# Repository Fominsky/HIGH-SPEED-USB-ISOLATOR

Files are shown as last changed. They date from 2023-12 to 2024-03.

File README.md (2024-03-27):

# High-speed USB isolator based on ADuM3165/ADuM3166

When connecting a USB device to a PC or laptop, there is a risk that the device may be faulty or may fail during operation. This is especially relevant during the development and debugging of devices that connects to your PC.

Connecting a malfunctioning USB device can easily lead to the failure of the USB hub in your PC, and in the case of laptops, the hub is often located on the same substrate as the processor. Thus, there is a risk that if something goes wrong, you will have to replace the processor in your laptop.

A USB isolator will protect your PC from USB-related issues. In the worst-case scenario, the ADuM3165/6 chip itself may fail, but your PC should be fine.

## Description
The device has 3 USB ports: Host USB, External Power USB, and Device USB.
Host USB is connected to your computer, Device USB is connected to your device that needs to be isolated, and External Power USB is connected to an external power source for powering the device connected to the Device USB port.

The device has its own low-power galvanically isolated DC-DC converter. The DC-DC converter also has converter overload protection. Therefore, the device can be used without external power for communication with low-power devices or devices that have their own power source.

The maximum current of the DC-DC converter is 200 mA. If this value is exceeded, the load is disconnected, and the "Overload" red LED lights up. The load will be disconnected either until the protection is reset by pressing SW1 button (Reset_Button) or until the USB is disconnected from the host USB and reconnected. 

To connect more powerful loads, you can use the External Power USB port. It is important to note that this USB is not isolated from the Device USB but is not electrically connected to the Host USB. A good solution would be to connect a power adapter from a mobile device to the external power USB.

When external power is connected, the built-in DC-DC converter is disabled. Note: as I mentioned before, the overload protection only works with the built-in DC-DC converter, so the overload protection is also disabled.

##

This Repository contains Gerber files, BOM, and step model. All you need to make an isolator. 





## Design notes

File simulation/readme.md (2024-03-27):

Simulation completed with https://www.falstad.com/circuit/circuitjs.html

When the load resistance is reduced below 24.8 ohms, a current greater than 200 mA flows through the load. 
The overload protection circuit triggers and turn off the transistor. 
During the operation of the protection and turning off the transistor, the simulation may experience some slight freezing.



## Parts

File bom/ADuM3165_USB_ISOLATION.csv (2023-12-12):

Source: | E:\Hardware\ADuM3165_USB_ISOLATION\ADuM3165_USB_ISOLATION_1.2\ADuM3165_USB_ISOLATION.kicad_sch
Date: | 12.12.2023 14:20:17
Tool: | Eeschema 7.0.9
Generator: | D:\Programs\KiCad\7.0\bin\scripting\plugins/bom_csv_grouped_by_value.py
Component Count: | 61
Collated Components:
Item | Qty | Reference(s) | Value | LibPart | Footprint | Datasheet | DNP | Digikey link | Name | Voltage
1 | 8 | C1, C2, C6, C7, C11, C12, C13, C14 | 0.1uF | Device:C_Small | Capacitor_SMD:C_0603_1608Metric | https://media.digikey.com/pdf/Data%20Sheets/Samsung%20PDFs/CL10B104KB8NFNC_Spec.pdf |  | https://www.digikey.fi/en/products/detail/samsung-electro-mechanics/CL10B104KB8NFNC/3890020 | CL10B104KB8NFNC | 50
2 | 2 | C3, C10 | 330pF | Device:C_Small | Capacitor_THT:C_Rect_L10.0mm_W3.0mm_P7.50mm_MKS4 | https://www.wima.de/wp-content/uploads/media/e_WIMA_FKP_3.pdf |  | https://www.digikey.fi/en/products/detail/wima/FKP3O103302B00KSSD/9370272 | FKP3O103302B00KSSD | 1000
3 | 2 | C4, C9 | 10uF | Device:C_Small | Capacitor_SMD:C_0805_2012Metric | https://media.digikey.com/pdf/Data%20Sheets/Samsung%20PDFs/CL21A106KOQNNNG_Spec.pdf |  | https://www.digikey.fi/en/products/detail/samsung-electro-mechanics/CL21A106KOQNNNG/3894417 | CL21A106KOQNNNG | 16
4 | 2 | C5, C8 | 1uF | Device:C_Small | Capacitor_SMD:C_0603_1608Metric | https://media.digikey.com/pdf/Data%20Sheets/Samsung%20PDFs/CL10A105KB8NNNC_Spec.pdf |  | https://www.digikey.fi/en/products/detail/samsung-electro-mechanics/CL10A105KB8NNNC/3887518 | CL10A105KB8NNNC | 50
5 | 2 | C15, C17 | 12pF | Device:C_Small | Capacitor_SMD:C_0603_1608Metric | http://www.passivecomponent.com/wp-content/uploads/datasheet/WTC_MLCC_General_Purpose.pdf |  | https://www.digikey.fi/en/products/detail/walsin-technology-corporation/0603N120J500CT/9354977 | 0603N120J500CT | 50
6 | 1 | D1 | Red | Device:LED | LED_SMD:LED_0603_1608Metric | https://optoelectronics.liteon.com/upload/download/DS22-2000-210/LTST-S270KRKT.pdf |  | https://www.digikey.fi/en/products/detail/liteon/LTST-S270KRKT/386895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 | LTST-S270KRKT
7 | 2 | D2, D5 | 10v 3A | Device:D_Schottky | Diode_SMD:D_SOD-323 | https://www.infineon.com/dgdl/bat60bseries.pdf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 |  | https://www.digikey.fi/en/products/detail/infineon-technologies/BAT60BE6327HTSA1/1280935 | BAT60BE6327HTSA1 | 10v
8 | 1 | D3 | Blue | Device:LED | LED_SMD:LED_0603_1608Metric | https://optoelectronics.liteon.com/upload/download/DS22-2000-175/LTST-S270TBKT.pdf |  | https://www.digikey.fi/en/products/detail/lite-on-inc/ltst-s270tbkt/573548 | LTST-S270TBKT
9 | 1 | D4 | Green | Device:LED | LED_SMD:LED_0603_1608Metric | https://optoelectronics.liteon.com/upload/download/DS22-2000-226/LTST-S270KGKT.pdf |  | https://www.digikey.fi/en/products/detail/lite-on-inc/ltst-s270kgkt/386893 | LTST-S270KGKT
10 | 1 | D6 | Or | Device:LED | LED_SMD:LED_0603_1608Metric | https://optoelectronics.liteon.com/upload/download/DS22-2000-209/LTST-S270KFKT.pdf |  | https://www.digikey.fi/en/products/detail/lite-on-inc/ltst-s270kfkt/386891 | LTST-S270KFKT
11 | 1 | DCDC1 | RFMM-0505S | User_lib:RFMM-0505S | User_Lib:RFMM_RFB0505S | https://recom-power.com/pdf/Econoline/RFMM.pdf |  | https://www.digikey.fi/en/products/detail/recom-power/RFMM-0505S/8550768?s=N4IgTCBcDaIEoDECySC0AGArFgyiAugL5A | RFMM-0505S
12 | 2 | J1, J2 | USB_C_Receptacle_USB2.0 | Connector:USB_C_Receptacle_USB2.0 | Connector_USB:USB_C_Receptacle_GCT_USB4105-xx-A_16P_TopMnt_Horizontal | https://gct.co/files/drawings/usb4105.pdf |  | https://www.digikey.fi/en/products/detail/gct/USB4105-GF-A/11198441 | USB4105-GF-A
13 | 1 | J3 | USB_A | Connector:USB_A | Connector_USB:USB_A_CONNFLY_DS1095-WNR0 | http://www.on-shore.com/wp-content/uploads/USB-A1HSXX.pdf |  | https://www.digikey.fi/en/products/detail/on-shore-technology-inc/USB-A1HSW6/2677750 | USB-A1HSW6
14 | 1 | L1 | 22 uH | pspice:INDUCTOR | Inductor_SMD:L_Taiyo-Yuden_MD-3030 | https://www.yuden.co.jp/productdata/catalog/wound04_e.pdf |  | https://www.digikey.fi/en/products/detail/taiyo-yuden/NR3015T220M/958032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 | NR3015T220M
15 | 1 | Q1 | AS2302 | Transistor_FET:DMN2230U | Package_TO_SOT_SMD:SOT-23 | https://media.digikey.com/pdf/Data%20Sheets/Anbon%20Semi%20PDFs/AS2302.pdf |  | https://www.digikey.fi/en/products/detail/anbon-semiconductor-int-l-limited/AS2302/16708469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 | AS2302 | 20V 3A
16 | 7 | R1, R3, R10, R15, R18, R25, R26 | 5k1 | Device:R | Resistor_SMD:R_0603_1608Metric | https://www.seielect.com/Catalog/SEI-RNCP.pdf |  | https://www.digikey.fi/en/products/detail/stackpole-electronics-inc/RNCP0603FTD1K00/2240106 | RNCP0603FTD1K00
17 | 7 | R2, R5, R6, R7, R12, R13, R14 | 1k | Device:R | Resistor_SMD:R_0603_1608Metric | https://www.seielect.com/Catalog/SEI-RNCP.pdf |  | https://www.digikey.fi/en/products/detail/stackpole-electronics-inc/RNCP0603FTD1K00/2240106 | RNCP0603FTD1K00
18 | 3 | R4, R11, R23 | 1.8k | Device:R | Resistor_SMD:R_0603_1608Metric | https://www.yageo.com/upload/media/product/productsearch/datasheet/rchip/PYu-RC_Group_51_RoHS_L_12.pdf |  | https://www.digikey.fi/en/products/detail/yageo/RC0603FR-101K8L/14008224 | RC0603FR-101K8L
19 | 3 | R8, R16, R19 | 24k | Device:R | Resistor_SMD:R_0603_1608Metric | https://www.yageo.com/upload/media/product/productsearch/datasheet/rchip/PYu-RC_Group_51_RoHS_L_12.pdf |  | https://www.digikey.fi/en/products/detail/yageo/RC0603FR-0724KL/727076 | RC0603FR-0724KL
20 | 1 | R17 | 560 | Device:R | Resistor_SMD:R_0603_1608Metric | https://www.yageo.com/upload/media/product/productsearch/datasheet/rchip/PYu-RC_Group_51_RoHS_L_12.pdf |  | https://www.digikey.fi/en/products/detail/yageo/RC0603JR-07560RL/726805 | RC0603JR-07560RL
21 | 2 | R20, R21 | 1 | Device:R | Resistor_SMD:R_0603_1608Metric | https://www.yageo.com/upload/media/product/productsearch/datasheet/rchip/PYu-AC_51_RoHS_L_9.pdf |  | https://www.digikey.fi/en/products/detail/yageo/AC0603FR-071RL/5895901 | AC0603FR-071RL
22 | 2 | R24, R27 | 0 | Device:R | Resistor_SMD:R_0603_1608Metric | https://www.yageo.com/upload/media/product/productsearch/datasheet/rchip/PYu-RC_Group_51_RoHS_L_12.pdf |  | https://www.digikey.fi/en/products/detail/yageo/RC0603JR-070RL/726675 | RC0603JR-070RL
23 | 1 | SW1 | Reset_Button | Switch:SW_Push | Button_Switch_THT:SW_Tactile_SPST_Angled_PTS645Vx58-2LFS | https://spec_sheets.e-switch.com/specs/P010309.pdf |  | https://www.digikey.fi/en/products/detail/e-switch/TL1105VF160Q/378974 | TL1105VF160Q
24 | 1 | U1 | MCP6004T-E/SL | Amplifier_Operational:MCP6004 | Package_SO:SOIC-14_3.9x8.7mm_P1.27mm | http://ww1.microchip.com/downloads/en/DeviceDoc/21733j.pdf |  | https://www.digikey.fi/en/products/detail/microchip-technology/MCP6004T-E-SL/683203 | MCP6004T-E/SL
25 | 1 | U2 | LTV-356T | Isolator:LTV-356T | Package_SO:SO-4_4.4x3.6mm_P2.54mm | http://optoelectronics.liteon.com/upload/download/DS70-2001-010/S_110_LTV-356T%2020140520.pdf |  | https://www.digikey.fi/en/products/detail/liteon/LTV-356T/385804 | LTV-356T
26 | 3 | U3, U5, U6 | D5V0P4UR6SO-7 | Power_Protection:NUP4202 | Package_TO_SOT_SMD:SOT-23-6 | https://www.digikey.fi/en/products/detail/diodes-incorporated/D5V0P4UR6SO-7/6052565 |  | https://www.digikey.fi/en/products/detail/diodes-incorporated/D5V0P4UR6SO-7/6052565 | D5V0P4UR6SO-7
27 | 1 | U4 | ADuM3165 | User_lib:ADuM3165 | Package_SO:SSOP-20_5.3x7.2mm_P0.65mm | https://au.mouser.com/datasheet/2/609/adum3165_3166-2946864.pdf |  | https://www.digikey.fi/en/products/detail/analog-devices-inc/ADUM3165BRSZ/16580732 | ADuM3165
28 | 1 | Y1 | 24MHz | Device:Crystal_GND24 | Crystal:Crystal_SMD_2016-4Pin_2.0x1.6mm | https://ecsxtal.com/store/pdf/ECX-1637B.pdf |  | https://www.digikey.fi/en/products/detail/ecs-inc/ECS-240-12-37B-CKY-TR/9838851 | ECS-240-12-37B-CKY-TR

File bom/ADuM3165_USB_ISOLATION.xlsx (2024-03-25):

Column1 | Column2 | Column3 | Column10 | Column4 | Column9 | Column11
Source: | E:\Hardware\ADuM3165_USB_ISOLATION\ADuM3165_USB_ISOLATION_1.2\ADuM3165_USB_ISOLATION.kicad_sch
Date: | 12.12.2023 14:20:17
Tool: | Eeschema 7.0.9
Generator: | D:\Programs\KiCad\7.0\bin\scripting\plugins/bom_csv_grouped_by_value.py
Component Count: | 61
Collated Components:
Item | Qty | Reference(s) | Name | Value | Digikey link | Voltage
1 | 8 | C1, C2, C6, C7, C11, C12, C13, C14 | CL10B104KB8NFNC | 0.1uF | https://www.digikey.fi/en/products/detail/samsung-electro-mechanics/CL10B104KB8NFNC/3890020 | 50
2 | 2 | C3, C10 | FKP3O103302B00KSSD | 330pF | https://www.digikey.fi/en/products/detail/wima/FKP3O103302B00KSSD/9370272 | 1000
3 | 2 | C4, C9 | CL21A106KOQNNNG | 10uF | https://www.digikey.fi/en/products/detail/samsung-electro-mechanics/CL21A106KOQNNNG/3894417 | 16
4 | 2 | C5, C8 | CL10A105KB8NNNC | 1uF | https://www.digikey.fi/en/products/detail/samsung-electro-mechanics/CL10A105KB8NNNC/3887518 | 50
5 | 2 | C15, C17 | 0603N120J500CT | 12pF | https://www.digikey.fi/en/products/detail/walsin-technology-corporation/0603N120J500CT/9354977 | 50
6 | 1 | D1 | LTST-S270KRKT | Red | https://www.digikey.fi/en/products/detail/liteon/LTST-S270KRKT/386895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
7 | 2 | D2, D5 | BAT60BE6327HTSA1 | 10v 3A | https://www.digikey.fi/en/products/detail/infineon-technologies/BAT60BE6327HTSA1/1280935 | 10v
8 | 1 | D3 | LTST-S270TBKT | Blue | https://www.digikey.fi/en/products/detail/lite-on-inc/ltst-s270tbkt/573548
9 | 1 | D4 | LTST-S270KGKT | Green | https://www.digikey.fi/en/products/detail/lite-on-inc/ltst-s270kgkt/386893
10 | 1 | D6 | LTST-S270KFKT | Or | https://www.digikey.fi/en/products/detail/lite-on-inc/ltst-s270kfkt/386891
11 | 1 | DCDC1 | RFMM-0505S | RFMM-0505S | https://www.digikey.fi/en/products/detail/recom-power/RFMM-0505S/8550768?s=N4IgTCBcDaIEoDECySC0AGArFgyiAugL5A
12 | 2 | J1, J2 | USB4105-GF-A | USB_C_Receptacle_USB2.0 | https://www.digikey.fi/en/products/detail/gct/USB4105-GF-A/11198441
13 | 1 | J3 | USB-A1HSW6 | USB_A | https://www.digikey.fi/en/products/detail/on-shore-technology-inc/USB-A1HSW6/2677750
14 | 1 | L1 | NR3015T220M | 22 uH | https://www.digikey.fi/en/products/detail/taiyo-yuden/NR3015T220M/958032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
15 | 1 | Q1 | AS2302 | AS2302 | https://www.digikey.fi/en/products/detail/anbon-semiconductor-int-l-limited/AS2302/16708469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 | 20V 3A
16 | 7 | R1, R3, R10, R15, R18, R25, R26 | RNCP0603FTD1K00 | 5k1 | https://www.digikey.fi/en/products/detail/stackpole-electronics-inc/RNCP0603FTD1K00/2240106
17 | 7 | R2, R5, R6, R7, R12, R13, R14 | RNCP0603FTD1K00 | 1k | https://www.digikey.fi/en/products/detail/stackpole-electronics-inc/RNCP0603FTD1K00/2240106
18 | 3 | R4, R11, R23 | RC0603FR-101K8L | 1.8k | https://www.digikey.fi/en/products/detail/yageo/RC0603FR-101K8L/14008224
19 | 3 | R8, R16, R19 | RC0603FR-0724KL | 24k | https://www.digikey.fi/en/products/detail/yageo/RC0603FR-0724KL/727076
20 | 1 | R17 | RC0603JR-07560RL | 560 | https://www.digikey.fi/en/products/detail/yageo/RC0603JR-07560RL/726805
21 | 2 | R20, R21 | AC0603FR-071RL | 1 | https://www.digikey.fi/en/products/detail/yageo/AC0603FR-071RL/5895901
22 | 2 | R24, R27 | RC0603JR-070RL | 0 | https://www.digikey.fi/en/products/detail/yageo/RC0603JR-070RL/726675
23 | 1 | SW1 | TL1105VF160Q | Reset_Button | https://www.digikey.fi/en/products/detail/e-switch/TL1105VF160Q/378974
24 | 1 | U1 | MCP6004T-E/SL | MCP6004T-E/SL | https://www.digikey.fi/en/products/detail/microchip-technology/MCP6004T-E-SL/683203
25 | 1 | U2 | LTV-356T | LTV-356T | https://www.digikey.fi/en/products/detail/liteon/LTV-356T/385804
26 | 3 | U3, U5, U6 | D5V0P4UR6SO-7 | D5V0P4UR6SO-7 | https://www.digikey.fi/en/products/detail/diodes-incorporated/D5V0P4UR6SO-7/6052565
27 | 1 | U4 | ADuM3165 | ADuM3165 | https://www.digikey.fi/en/products/detail/analog-devices-inc/ADUM3165BRSZ/16580732
28 | 1 | Y1 | ECS-240-12-37B-CKY-TR | 24MHz | https://www.digikey.fi/en/products/detail/ecs-inc/ECS-240-12-37B-CKY-TR/9838851

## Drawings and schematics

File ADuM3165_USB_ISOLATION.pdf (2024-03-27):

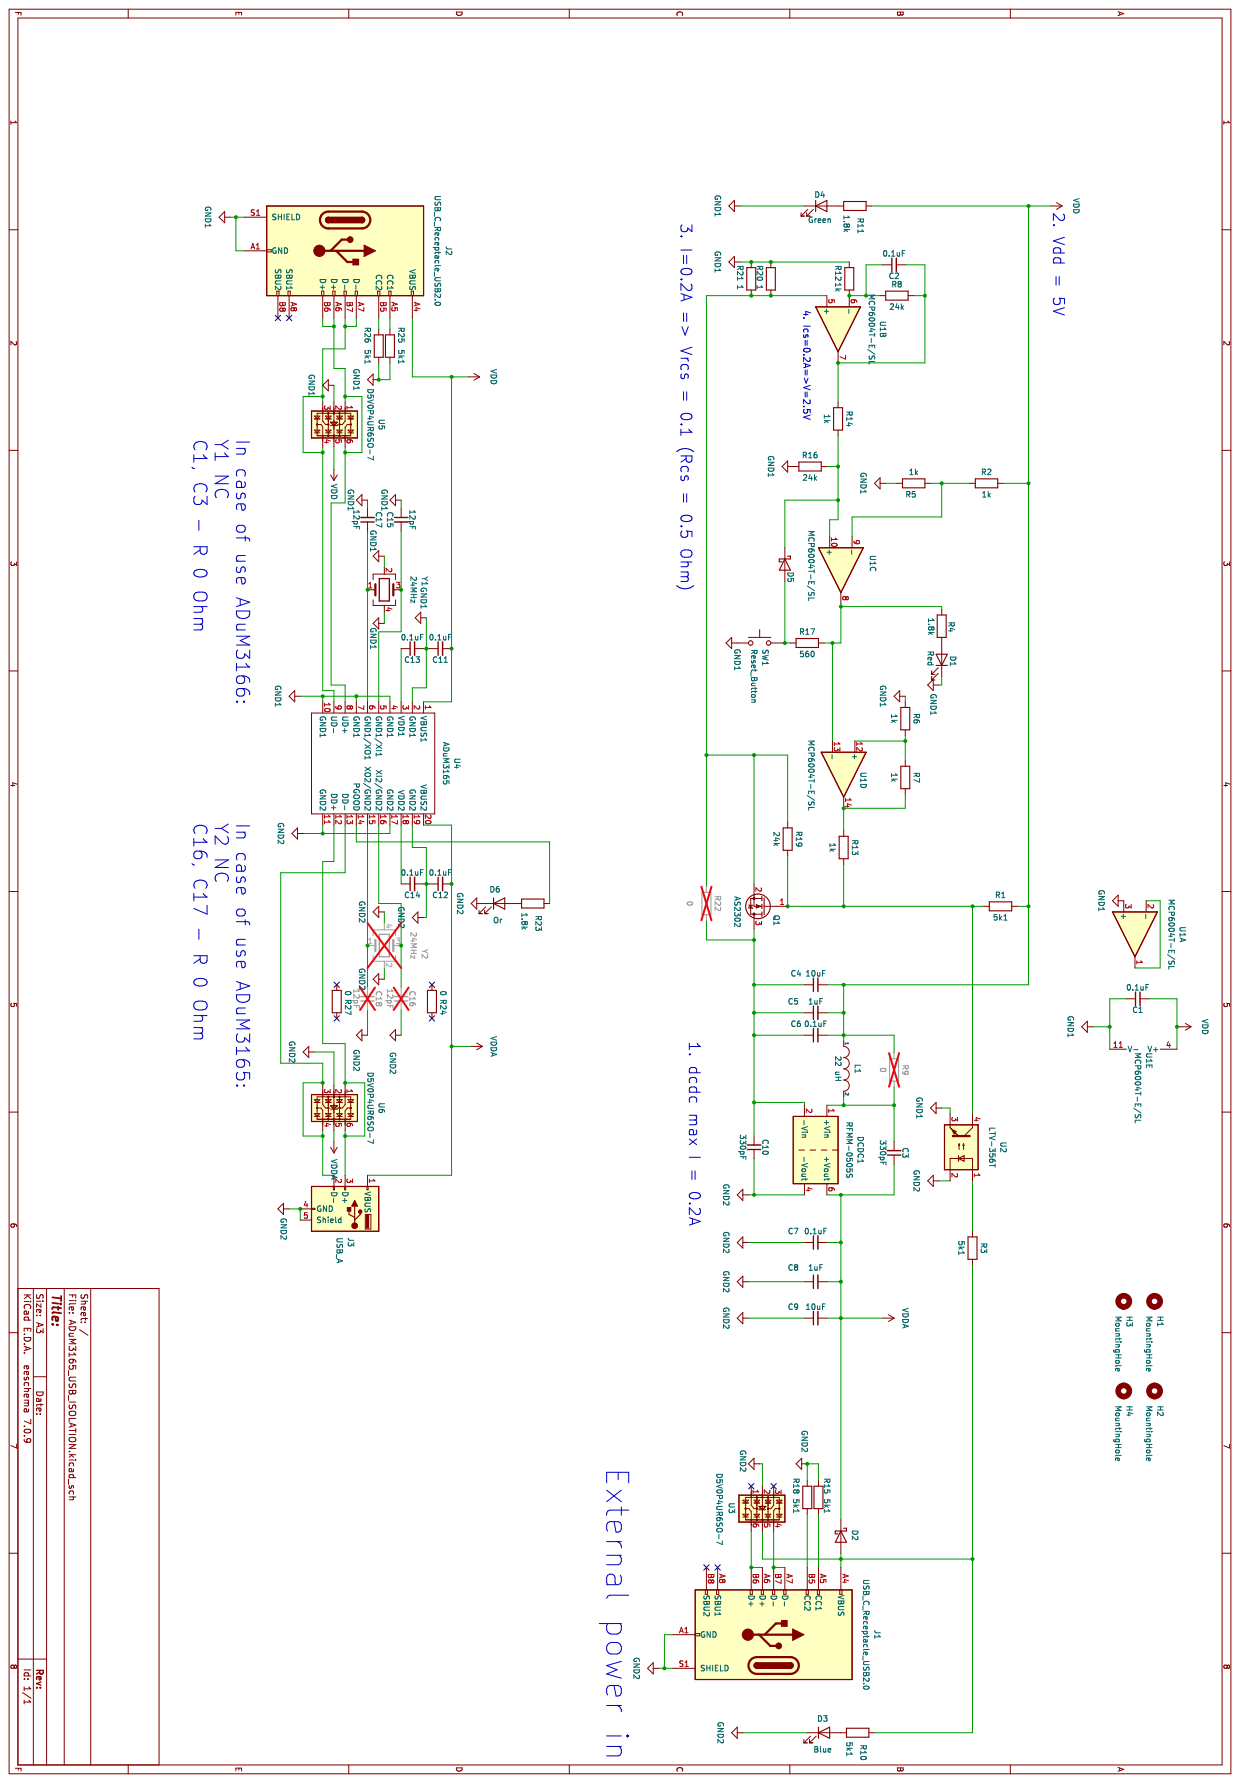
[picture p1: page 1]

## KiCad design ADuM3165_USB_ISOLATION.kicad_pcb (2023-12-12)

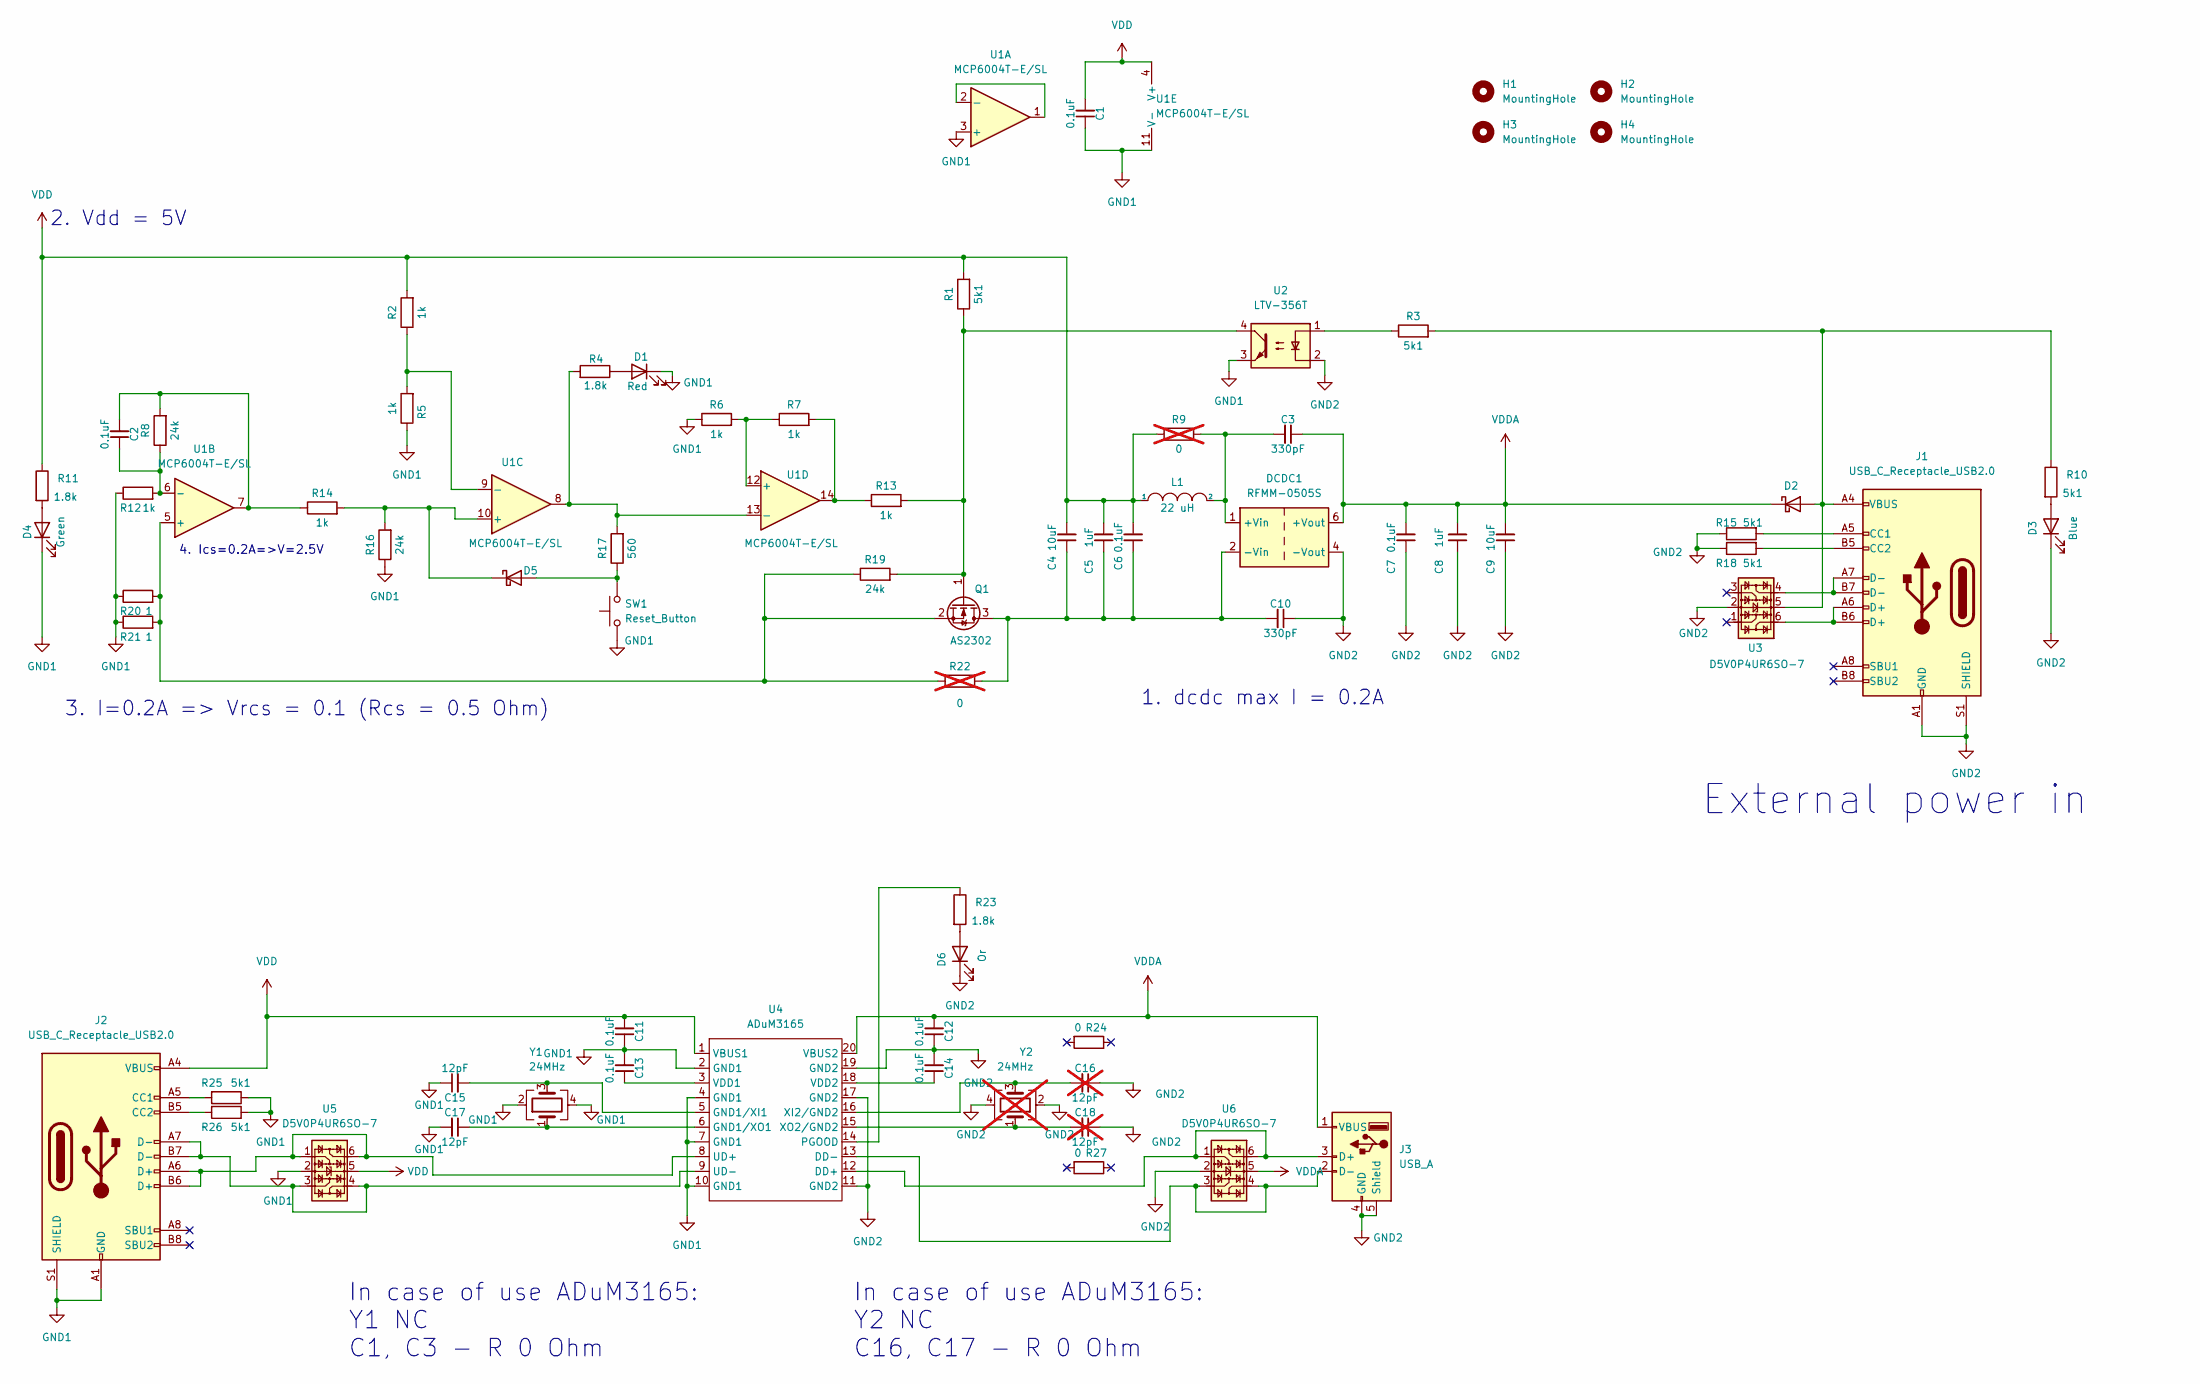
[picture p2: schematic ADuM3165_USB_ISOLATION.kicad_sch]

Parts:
C1, C2, C6, C7, C11, C12, C13, C14: 0.1uF; C_0603_1608Metric; Voltage 50
C3, C10: 330pF; C_Rect_L10.0mm_W3.0mm_P7.50mm_MKS4; Voltage 1000
C4, C9: 10uF; C_0805_2012Metric; Voltage 16
C5, C8: 1uF; C_0603_1608Metric; Voltage 50
C15, C17: 12pF; C_0603_1608Metric; Voltage 50
C16, C18: 12pF; C_0603_1608Metric; Voltage 50; not fitted
D1: Red; LED_0603_1608Metric
D2, D5: 10v 3A; D_SOD-323; Voltage 10v
D3: Blue; LED_0603_1608Metric
D4: Green; LED_0603_1608Metric
D6: Or; LED_0603_1608Metric
DCDC1: RFMM-0505S; RFMM_RFB0505S
H1, H2, H3, H4: MountingHole; MountingHole_3.2mm_M3_DIN965
J1, J2: USB_C_Receptacle_USB2.0; USB_C_Receptacle_GCT_USB4105-xx-A_16P_TopMnt_Horizontal
J3: USB_A; USB_A_CONNFLY_DS1095-WNR0
L1: 22 uH; L_Taiyo-Yuden_MD-3030
Q1: AS2302; SOT-23; Voltage 20V 3A
R1, R3, R10, R15, R18, R25, R26: 5k1; R_0603_1608Metric
R2, R5, R6, R7, R12, R13, R14: 1k; R_0603_1608Metric
R4, R11, R23: 1.8k; R_0603_1608Metric
R8, R16, R19: 24k; R_0603_1608Metric
R9, R22: 0; R_0603_1608Metric; not fitted
R17: 560; R_0603_1608Metric
R20, R21: 1; R_0603_1608Metric
R24, R27: 0; R_0603_1608Metric
SW1: Reset_Button; SW_Tactile_SPST_Angled_PTS645Vx58-2LFS
U1: MCP6004T-E/SL; SOIC-14_3.9x8.7mm_P1.27mm
U2: LTV-356T; SO-4_4.4x3.6mm_P2.54mm
U3, U5, U6: D5V0P4UR6SO-7; SOT-23-6
U4: ADuM3165; SSOP-20_5.3x7.2mm_P0.65mm
Y1: 24MHz; Crystal_SMD_2016-4Pin_2.0x1.6mm
Y2: 24MHz; Crystal_SMD_2016-4Pin_2.0x1.6mm; not fitted

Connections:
GND1: C1.1, C11.1, C13.2, C15.1, C17.2, D1.1 (K), D4.1 (K), J2.A1 (GND), J2.A12 (GND), J2.B1 (GND), J2.B12 (GND), J2.S1 (SHIELD), R5.1, R6.1, R12.1, R16.1, R20.1, R21.1, R25.1, R26.1, SW1.1, U1.3 (+), U1.11 (V-), U2.3, U4.2 (GND1), U4.4 (GND1), U4.7 (GND1), U4.10 (GND1), U5.2, Y1.2, Y1.4
GND2: C7.1, C8.1, C9.1, C10.1, C12.1, C14.2, C16.1, C18.1, D3.1 (K), D6.1 (K), DCDC1.4 (-Vout), DCDC1.5 (-Vout), J1.A1 (GND), J1.A12 (GND), J1.B1 (GND), J1.B12 (GND), J1.S1 (SHIELD), J3.4 (GND), J3.5 (Shield), R15.1, R18.1, U2.2, U3.2, U4.11 (GND2), U4.17 (GND2), U4.19 (GND2), U6.2, Y2.2, Y2.4
unnamed: C2.2, R8.2, R14.1, U1.7
unnamed: D1.2 (A), R4.1
unnamed: D2.2 (A), J1.A4 (VBUS), J1.A9 (VBUS), J1.B4 (VBUS), J1.B9 (VBUS), R3.2, R10.1, U3.5
unnamed: D3.2 (A), R10.2
unnamed: D4.2 (A), R11.2
unnamed: D5.2 (A), R17.1, SW1.2
unnamed: D5.1 (K), R14.2, R16.2, U1.10 (+)
unnamed: D6.2 (A), R23.2
unnamed: C3.2, DCDC1.1 (+Vin), L1.2, R9.2
unnamed: C4.1, C5.1, C6.1, C10.2, DCDC1.2 (-Vin), Q1.3 (D), R22.2
unnamed: J1.A5 (CC1), R15.2
unnamed: J1.B5 (CC2), R18.2
unnamed: J1.A6 (D+), J1.B6 (D+), U3.6
unnamed: J1.A7 (D-), J1.B7 (D-), U3.4
unnamed: J2.A5 (CC1), R25.2
unnamed: J2.B5 (CC2), R26.2
unnamed: J3.3 (D+), U4.12 (DD+), U6.1, U6.6
unnamed: J3.2 (D-), U4.13 (DD-), U6.3, U6.4
unnamed: Q1.1 (G), R1.1, R13.2, R19.2, U2.4
unnamed: Q1.2 (S), R19.1, R20.2, R21.2, R22.1, U1.5 (+)
unnamed: R3.1, U2.1
unnamed: R7.2, R13.1, U1.14
unnamed: U1.1, U1.2 (-)
unnamed: C2.1, R8.1, R12.2, U1.6 (-)
unnamed: R2.1, R5.2, U1.9 (-)
unnamed: R6.2, R7.1, U1.12 (+)
unnamed: R4.2, R17.2, U1.8, U1.13 (-)
unnamed: C15.2, U4.5 (GND1/XI1), Y1.3
unnamed: C17.1, U4.6 (GND1/XO1), Y1.1
unnamed: R23.1, U4.14 (PGOOD)
unnamed: J2.A6 (D+), J2.B6 (D+), U4.8 (UD+), U5.1, U5.6
unnamed: J2.A7 (D-), J2.B7 (D-), U4.9 (UD-), U5.3, U5.4
unnamed: C13.1, U4.3 (VDD1)
unnamed: C14.1, U4.18 (VDD2)
unnamed: C16.2, U4.16 (XI2/GND2), Y2.3
unnamed: C18.2, U4.15 (XO2/GND2), Y2.1
VDD: C1.2, C4.2, C5.2, C6.2, C11.2, J2.A4 (VBUS), J2.A9 (VBUS), J2.B4 (VBUS), J2.B9 (VBUS), L1.1, R1.2, R2.2, R9.1, R11.1, U1.4 (V+), U4.1 (VBUS1), U5.5
VDDA: C3.1, C7.2, C8.2, C9.2, C12.2, D2.1 (K), DCDC1.6 (+Vout), DCDC1.7 (+Vout), J3.1 (VBUS), U4.20 (VBUS2), U6.5

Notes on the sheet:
3. I=0.2A => Vrcs = 0.1 (Rcs = 0.5 Ohm)
4. Ics=0.2A=>V=2.5V
In case of use ADuM3165: Y1 NC C1, C3 - R 0 Ohm
In case of use ADuM3165: Y2 NC C16, C17 - R 0 Ohm
1. dcdc max I = 0.2A
External power in
2. Vdd = 5V

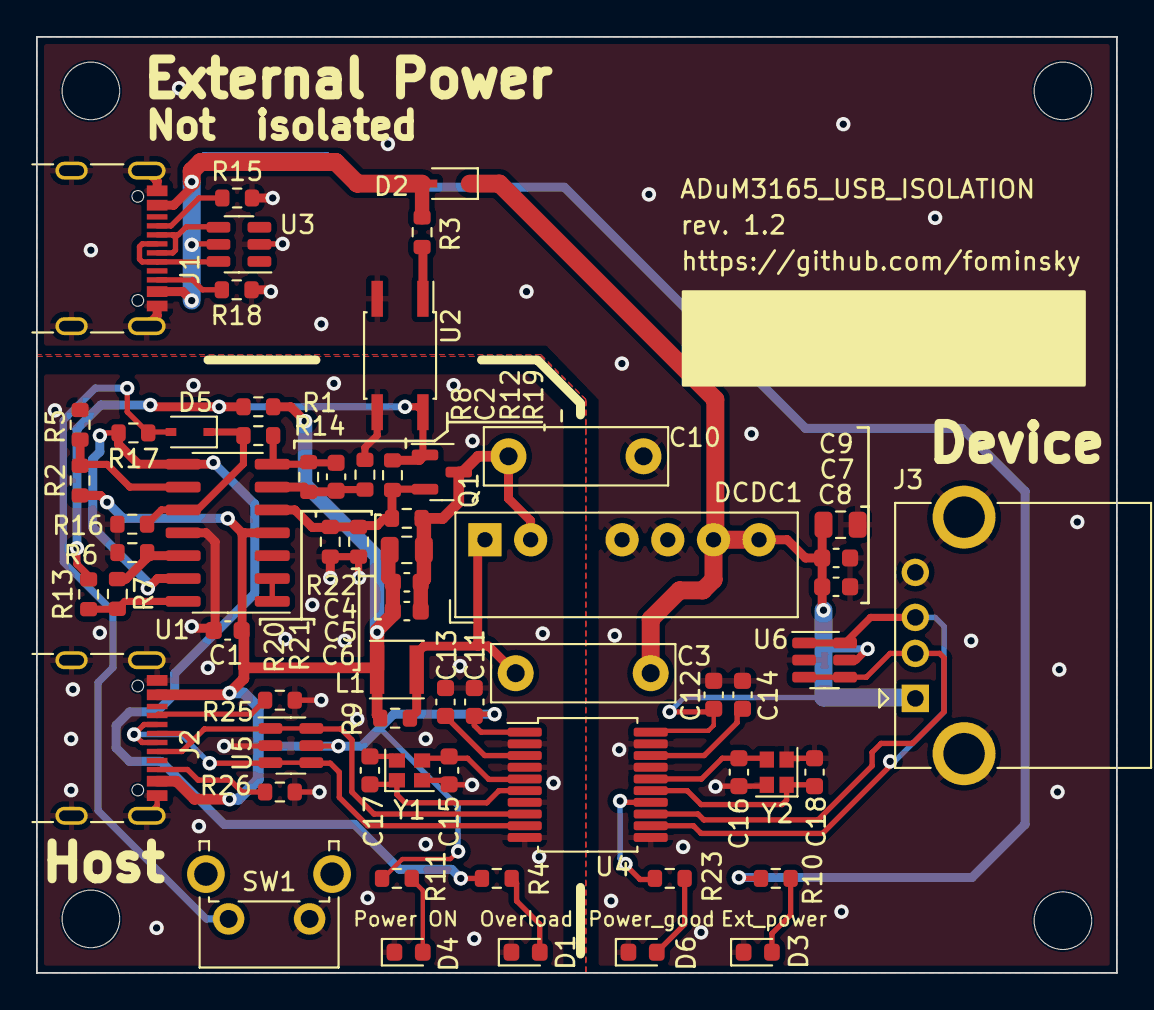
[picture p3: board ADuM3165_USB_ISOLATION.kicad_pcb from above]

Board: 2 copper layers, 60.0 x 52.0 mm, 68 parts (0 on the bottom side), 40 nets.

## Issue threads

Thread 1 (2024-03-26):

Working troublesheeting

Fominsky, 2024-03-26:
Here, questions regarding the functionality of the USB isolator can be asked.

Answers for some questionc could be found [here](https://github.com/Fominsky/HIGH-SPEED-USB-ISOLATOR/commit/2bc43586c228aba4573ba25b7acf777d7a8741d8) and [here](https://github.com/Fominsky/HIGH-SPEED-USB-ISOLATOR/commit/8b8e6121aa6792d75134bf91e14221efd30d75ce)

Fominsky, 2024-03-26:
Here is a photo of one of the soldered devices.
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

Green LED lights if there is power from the host USB;
Red LED lights if dc-dc converter overload protection has worked;
Orange LED lights if all necessary powers for ADuM3165/6 are present and quartz clocks;
Blue LED lights if external power is present.

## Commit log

2023-12-12 init comit
    [ADuM3165_USB_ISOLATION-B_Cu.gbr, ADuM3165_USB_ISOLATION-B_Mask.gbr, ADuM3165_USB_ISOLATION-B_Paste.gbr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]
2023-12-13 bom fix, gitignores added
    [ADuM3165_USB_ISOLATION.xlsx]
2024-03-25 schematic is updated to actual version
2024-03-27 change note on schematic
    [ADuM3165_USB_ISOLATION.kicad_sch]
